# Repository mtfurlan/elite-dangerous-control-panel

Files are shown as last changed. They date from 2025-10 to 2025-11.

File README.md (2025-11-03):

# RP2040 TinyUSB HID elite dangerous controller
A control panel for Elite Dangerous.

It takes input from the game's
[Status.json](https://elite-journal.readthedocs.io/en/latest/Status%20File.html)
and sends it over HID to the control panel.

That way we can have switches that act like buttons, as well as LEDs.

## HID notes
I had some Issues getting tinyusb working, I tried adafruit's port under platformio and too many things there were annoying and broken.
So eventaully I just ended up using the rp2040 pico-sdk and tinyusb directly.

`.lvimrc` to configure [`vim-ale`](https://github.com/dense-analysis/ale) cause it can't fully get stuff from `compile_commands.json` [yet](https://github.com/dense-analysis/ale/issues/3328)

### USB HID
* [Introduction to HID report descriptors](https://docs.kernel.org/hid/hidintro.html)
* spec
  * [HID 1.11 spec](https://www.usb.org/sites/default/files/hid1_11.pdf)
  * [HID Usage Tables](https://usb.org/sites/default/files/hut1_6.pdf): has usage pages and usage tags and other stuff

* input: data from device -> host like keyboard or joystick
* output: data from host -> device, like keyboard LEDs
* feature report: other stuff
  > "Feature"s are not meant to be consumed by the end user and define configuration options for the device.

#### linux support of HID
Unfortunately, linux doesn't support stuff like weird simulation buttons, so
the only real options are gamepad buttons or keyboard buttons.

[Look at how little of sim is covered](https://github.com/torvalds/linux/blob/master/drivers/hid/hid-input.c#L797-L806).

#### decoding descriptor reports
* [hidrdd](https://github.com/abend0c1/hidrdd)
  * `alias hidrdd="rexx ~/src/hidrdd/rd.rex -i ~/src/hidrdd/rd.conf --no-struct"`
  * `hidrdd -bf /sys/bus/hid/devices/0003\:CAFE\:4003.0060/report_descriptor`
* [online USB Descriptor and Request Parser](http://eleccelerator.com/usbdescreqparser/)
  * `xxd -p /sys/bus/hid/devices/0003\:CAFE\:4003.0060/report_descriptor | tr -d '\n' | copyToClipboard`

#### host side hid tools
```
hidapitester --vidpid CAFE:4003 --open --length 3 --send-output 1,0x00,0x0
```

python [hid](https://pypi.org/project/hid/) wraps [libusb hidapi](https://libusb.info/hidapi/group__API.html)
```
import hid
with hid.Device(vid, pid) as h:
    h.write(bytes([0x01, 0x42, 0, 0, 0]))
```

udev:
```
SUBSYSTEMS=="usb", ATTRS{idVendor}=="cafe", MODE:="0666"
```

### Fun facts about windows
windows will just disregard hid devices with vendor pages without usage min/max, even though it's a vendor page

In actual windows, you can see a (misspelled) error in the device manager.

In wine, I'm not sure how to get any error message.

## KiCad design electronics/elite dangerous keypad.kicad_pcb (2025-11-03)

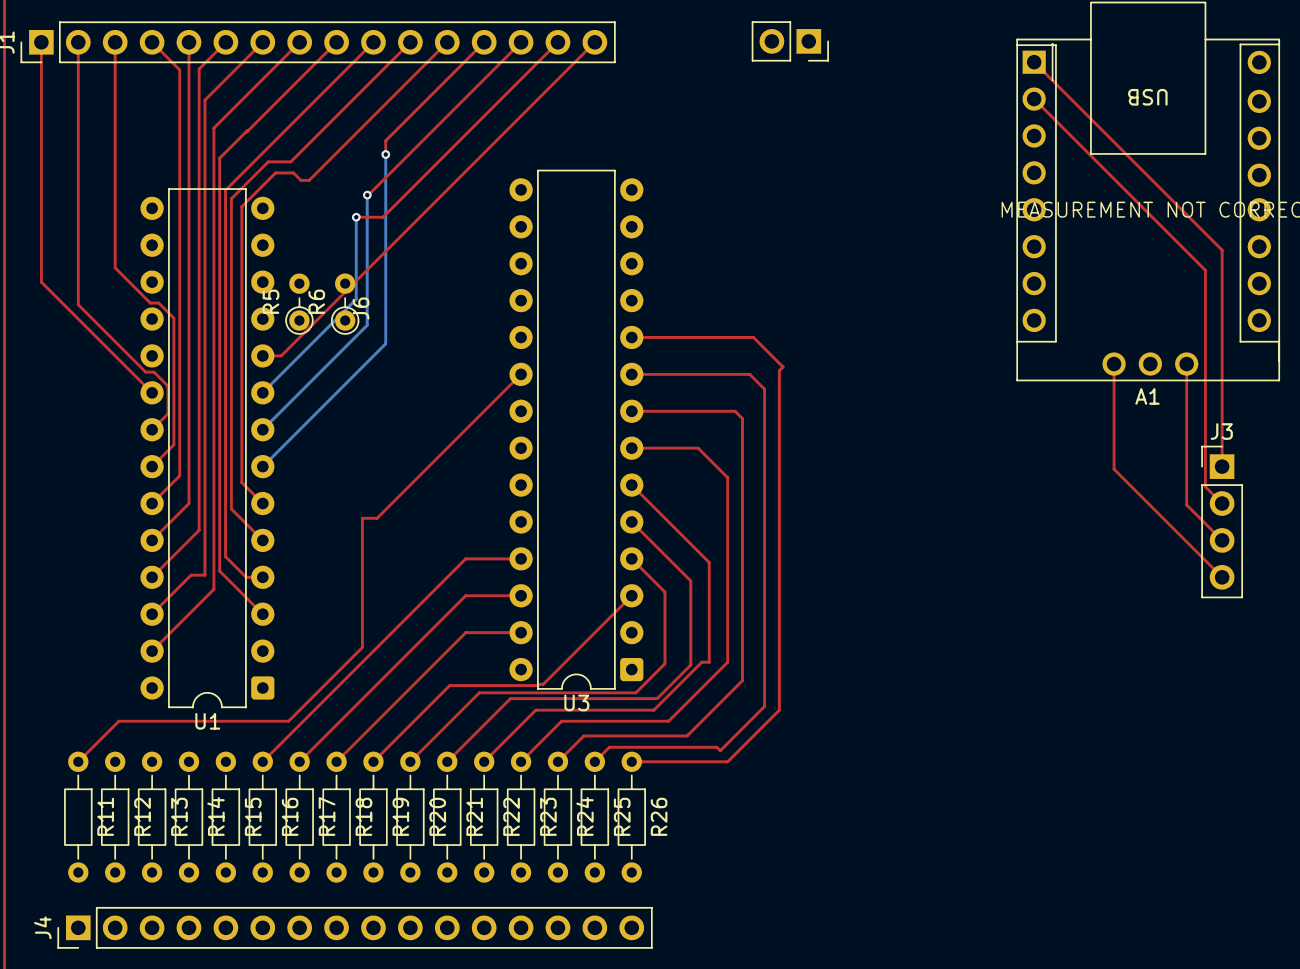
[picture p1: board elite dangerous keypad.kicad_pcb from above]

Board: 2 copper layers, 25 parts (0 on the bottom side), 55 nets.

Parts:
A1: Tiny2040; Arduino_Nano
J1: button; PinHeader_1x16_P2.54mm_Vertical
J3: swd debug; PinHeader_1x04_P2.54mm_Vertical
J4: led; PinHeader_1x16_P2.54mm_Vertical
J6: Conn_01x02; PinSocket_1x02_P2.54mm_Vertical
R5, R6: 1k5; R_Axial_DIN0204_L3.6mm_D1.6mm_P2.54mm_Vertical
R11, R12, R13, R14, R15, R16, R17, R18, R19, R20, R21, R22, R23, R24, R25, R26: R; R_Axial_DIN0204_L3.6mm_D1.6mm_P7.62mm_Horizontal
U1, U3: MCP23018x-x-SP; DIP-28_W7.62mm

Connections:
+5V: A1.1 (5V), J3.1, J6.1, R5.1, R6.1, U1.11 (V_{DD}), U1.16 (~RESET), U3.11 (V_{DD}), U3.15 (ADDR), U3.16 (~RESET)
/B0: J1.1, U1.20 (GPA0)
/B1: J1.2, U1.21 (GPA1)
/B2: J1.3, U1.22 (GPA2)
/B3: J1.4, U1.23 (GPA3)
/B4: J1.5, U1.24 (GPA4)
/B5: J1.6, U1.25 (GPA5)
/B6: J1.7, U1.26 (GPA6)
/B7: J1.8, U1.27 (GPA7)
/B8: J1.9, U1.3 (GPB0)
/B9: J1.10, U1.4 (GPB1)
/B10: J1.11, U1.5 (GPB2)
/B11: J1.12, U1.6 (GPB3)
/B12: J1.13, U1.7 (GPB4)
/B13: J1.14, U1.8 (GPB5)
/B14: J1.15, U1.9 (GPB6)
/B15: J1.16, U1.10 (GPB7)
/L0: R11.1, U3.20 (GPA0)
/L1: R12.1, U3.21 (GPA1)
/L2: R13.1, U3.22 (GPA2)
/L3: R14.1, U3.23 (GPA3)
/L4: R15.1, U3.24 (GPA4)
/L5: R16.1, U3.25 (GPA5)
/L6: R17.1, U3.26 (GPA6)
/L7: R18.1, U3.27 (GPA7)
/L8: R19.1, U3.3 (GPB0)
/L9: R20.1, U3.4 (GPB1)
/L10: R21.1, U3.5 (GPB2)
/L11: R22.1, U3.6 (GPB3)
/L12: R23.1, U3.7 (GPB4)
/L13: R24.1, U3.8 (GPB5)
/L14: R25.1, U3.9 (GPB6)
/L15: R26.1, U3.10 (GPB7)
/MCU_INPUT_INT: A1.10 (6), U1.19 (INTA)
/SCL: A1.11 (5), R5.2, U1.12 (SCL), U3.12 (SCL)
/SDA: A1.12 (4), R6.2, U1.13 (SDA), U3.13 (SDA)
GND: A1.2 (GND), J3.2, J6.2, U1.1 (V_{SS}), U1.15 (ADDR), U3.1 (V_{SS})
unnamed: A1.SWD, J3.3
unnamed: A1.SWC, J3.4
unnamed: J4.1, R11.2
unnamed: J4.2, R12.2
unnamed: J4.3, R13.2
unnamed: J4.4, R14.2
unnamed: J4.5, R15.2
unnamed: J4.6, R16.2
unnamed: J4.7, R17.2
unnamed: J4.8, R18.2
unnamed: J4.9, R19.2
unnamed: J4.10, R20.2
unnamed: J4.11, R21.2
unnamed: J4.12, R22.2
unnamed: J4.13, R23.2
unnamed: J4.14, R24.2
unnamed: J4.15, R25.2
unnamed: J4.16, R26.2

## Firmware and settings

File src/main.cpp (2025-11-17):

#include <stdlib.h>

#include <bsp/board_api.h>
#include <hardware/i2c.h>
#include <pico/stdio.h>
#include <tusb.h>

#include <mcp23017.h>

#include "buttons.h"
#include "config_button.h"
#include "config_quadrature.h"
#include "config_smart.h"
#include "hid.h"
#include "led.h"
#include "usb_descriptors.h"


#define MCP_INPUT         0x20
#define MCP_OUTPUT        0x27
#define MCP_INPUT_IRQ_PIN 6


#define I2C_GPIO_PIN_SDA 4
#define I2C_GPIO_PIN_SCL 5


void hid_task(bool dirty, uint16_t* inputs);
static void send_hid_report(uint8_t report_id, uint16_t btn);


static Config* config[] = {
    new ConfigSmart(1,
                    1,
                    1,
                    [](hid_incoming_data_t* data) -> bool {
                        return data->Flags.fields.Landing_Gear_Down;
                    }),
    new ConfigSmart(2,
                    2,
                    2,
                    [](hid_incoming_data_t* data) -> bool {
                        return data->Flags.fields.LightsOn;
                    }),
    new ConfigSmart(3,
                    3,
                    3,
                    [](hid_incoming_data_t* data) -> bool {
                        return data->Flags.fields.Night_Vision;
                    }),
    new ConfigSmart(4,
                    4,
                    4,
                    [](hid_incoming_data_t* data) -> bool {
                        return data->Flags.fields.Hardpoints_Deployed;
                    }),
    new ConfigSmart(5,
                    5,
                    5,
                    [](hid_incoming_data_t* data) -> bool {
                        return data->Flags.fields.Cargo_Scoop_Deployed;
                    }),
    new ConfigButton(6, 6),
    new ConfigButton(7, 7),
    new ConfigButton(8, 8),
    new ConfigButton(9, 9),
    new ConfigButton(10, 10),
    new ConfigButton(11, 11),
    new ConfigButton(12, 12),
    new ConfigButton(13, 13),
    new ConfigQuadrature(14, 15, 14, 15),
    new ConfigButton(16, 16),
};

static led_state_t led_state = BLINK_NOT_MOUNTED;
static hid_incoming_data_t hid_incoming_data;


int main(void)
{
    // Initialize TinyUSB stack
    board_init();
    tusb_init();


    i2c_init(i2c0, 400000);
    gpio_set_function(I2C_GPIO_PIN_SDA, GPIO_FUNC_I2C);
    gpio_set_function(I2C_GPIO_PIN_SCL, GPIO_FUNC_I2C);
    gpio_pull_up(I2C_GPIO_PIN_SDA);
    gpio_pull_up(I2C_GPIO_PIN_SCL);

    int err = 0;
    err |= buttons_init(MCP_INPUT_IRQ_PIN, i2c0, MCP_INPUT);
    err |= led_init(i2c0, MCP_OUTPUT);

    // TinyUSB board init callback after init
    if (board_init_after_tusb) {
        board_init_after_tusb();
    }

    // let pico sdk use the first cdc interface for std io
    stdio_init_all();

    tud_task();

    bool fail = false;
    if (err != 0) {
        fail = true;
    } else {
        for (size_t i = 0; i < TU_ARRAY_SIZE(config); ++i) {
            Config* c = config[i];
            if ((err = c->init()) != 0) {
                sleep_ms(1000);
                printf("init failed for config %d bad: %d\n", i, err);
                fail = true;
            }
        }
    }

    if (fail) {
        while (true) {
            tud_task();
            led_error();
            printf("failed to init\n");
        }
    }

    printf("hello running");
    uint16_t button_data = 0;
    uint16_t output;
    uint16_t led_data;

    // main run loop
    while (1) {
        // TinyUSB device task | must be called regurlarly
        tud_task();

        bool dirty = buttons_task(&button_data);

        // input data: hid_incoming_data.leds
        // switch state: button_data
        for (size_t i = 0; i < TU_ARRAY_SIZE(config); ++i) {
            Config* c = config[i];
            dirty |= c->generateOutput(&output, button_data, &hid_incoming_data);
        }


        hid_task(dirty, &output);

        led_data = 0;
        for (size_t i = 0; i < TU_ARRAY_SIZE(config); ++i) {
            Config* c = config[i];
            c->setLED(&led_data, &hid_incoming_data);
        }

        led_task(led_state, led_data);
    }

    // indicate no error
    return 0;
}

//--------------------------------------------------------------------+
// Device callbacks
//--------------------------------------------------------------------+

// Invoked when device is mounted
void tud_mount_cb(void)
{
    led_state = BLINK_MOUNTED;
}

// Invoked when device is unmounted
void tud_umount_cb(void)
{
    led_state = BLINK_NOT_MOUNTED;
}

// Invoked when usb bus is suspended
// remote_wakeup_en : if host allow us  to perform remote wakeup
// Within 7ms, device must draw an average of current less than 2.5 mA from bus
void tud_suspend_cb(bool remote_wakeup_en)
{
    (void)remote_wakeup_en;
    led_state = BLINK_SUSPENDED;
}

// Invoked when usb bus is resumed
void tud_resume_cb(void)
{
    led_state = tud_mounted() ? BLINK_MOUNTED : BLINK_NOT_MOUNTED;
}

//--------------------------------------------------------------------+
// USB HID
//--------------------------------------------------------------------+
// Every 10ms, we will sent 1 report for each HID profile (keyboard, mouse etc ..)
// tud_hid_report_complete_cb() is used to send the next report after previous one is complete
static uint16_t btn;
void hid_task(bool dirty, uint16_t* inputs)
{
    btn = *inputs;
    // Poll every 10ms
    const uint32_t interval_ms = 10;
    static uint32_t start_ms = 0;

    if (!dirty && (board_millis() - start_ms < interval_ms)) {
        return; // not enough time
    }
    start_ms += interval_ms;

    // Remote wakeup
    if (tud_suspended() && btn) {
        // Wake up host if we are in suspend mode
        // and REMOTE_WAKEUP feature is enabled by host
        tud_remote_wakeup();
    } else {
        // Send the 1st of report chain, the rest will be sent by tud_hid_report_complete_cb()
        send_hid_report(REPORT_ID_GAMEPAD, btn);
    }
}

// Invoked when sent REPORT successfully to host
// Application can use this to send the next report
// Note: For composite reports, report[0] is report ID
void tud_hid_report_complete_cb(uint8_t instance, uint8_t const* report, uint16_t len)
{
    (void)instance;
    (void)len;

    uint8_t next_report_id = report[0] + 1u;

    if (next_report_id < REPORT_ID_COUNT) {
        send_hid_report(next_report_id, btn);
    }
}

// Invoked when received GET_REPORT control request
// Application must fill buffer report's content and return its length.
// Return zero will cause the stack to STALL request
uint16_t tud_hid_get_report_cb(uint8_t instance,
                               uint8_t report_id,
                               hid_report_type_t report_type,
                               uint8_t* buffer,
                               uint16_t reqlen)
{
    // TODO not Implemented
    (void)instance;
    (void)report_id;
    (void)report_type;
    (void)buffer;
    (void)reqlen;

    return 0;
}

// Invoked when received SET_REPORT control request or
// received data on OUT endpoint ( Report ID = 0, Type = 0 )
void tud_hid_set_report_cb(uint8_t instance,
                           uint8_t report_id,
                           hid_report_type_t report_type,
                           uint8_t const* buffer,
                           uint16_t bufsize)
{
    (void)instance;

    if (report_type == HID_REPORT_TYPE_OUTPUT) {
        // Set keyboard LED e.g Capslock, Numlock etc...
        if (report_id == REPORT_ID_GAMEPAD) {
            // bufsize should be (at least) 1
            if (bufsize != sizeof(hid_incoming_data_t)) {
                printf("got a weird size data from hid, reporrt id %d, expected %d bytes, got %d\n",
                       report_id,
                       sizeof(hid_incoming_data_t),
                       bufsize);
                return;
            }

            hid_incoming_data = *(hid_incoming_data_t*)buffer;

            printf("got data\n");
        } else {
            printf("got unexpected output repoort for id %d", report_id);
        }
    }
}

static void send_hid_report(uint8_t report_id, uint16_t btn)
{
    // skip if hid is not ready yet
    if (!tud_hid_ready())
        return;

    switch (report_id) {
        case REPORT_ID_GAMEPAD: {
            // use to avoid send multiple consecutive zero report for keyboard
            static bool has_gamepad_key = false;

            hid_button_report_t report = {
                .buttons = btn,
            };

            if (btn) {
                tud_hid_report(REPORT_ID_GAMEPAD, &report, sizeof(report));

                has_gamepad_key = true;
            } else {
                if (has_gamepad_key)
                    tud_hid_report(REPORT_ID_GAMEPAD, &report, sizeof(report));
                has_gamepad_key = false;
            }
        } break;

        default:
            break;
    }
}

//--------------------------------------------------------------------+
// USB CDC
//--------------------------------------------------------------------+

// callback when data is received on a CDC interface
void tud_cdc_rx_cb(uint8_t itf)
{
    // allocate buffer for the data in the stack
    uint8_t buf[CFG_TUD_CDC_RX_BUFSIZE];

    printf("RX CDC %d\n", itf);

    // read the available data
    // | IMPORTANT: also do this for CDC0 because otherwise
    // | you won't be able to print anymore to CDC0
    // | next time this function is called
    uint32_t count = tud_cdc_n_read(itf, buf, sizeof(buf));

    // check if the data was received on the second cdc interface
    if (itf == 1) {
        // process the received data
        buf[count] = 0; // null-terminate the string
        // now echo data back to the console on CDC 0
        printf("Received on CDC 1: %s\n", buf);

        // and echo back OK on CDC 1
        tud_cdc_n_write(itf, (uint8_t const*)"OK\r\n", 4);
        tud_cdc_n_write_flush(itf);
    }
}

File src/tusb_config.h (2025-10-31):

/**
 * Copyright (c) 2023 Raspberry Pi (Trading) Ltd.
 *
 * SPDX-License-Identifier: BSD-3-Clause
 */

#ifndef _TUSB_CONFIG_H_
#define _TUSB_CONFIG_H_

#ifdef __cplusplus
extern "C" {
#endif

#define CFG_TUD_ENABLED (1)

// Legacy RHPORT configuration
#define CFG_TUSB_RHPORT0_MODE (OPT_MODE_DEVICE | OPT_MODE_FULL_SPEED)
#ifndef BOARD_TUD_RHPORT
#define BOARD_TUD_RHPORT (0)
#endif
// end legacy RHPORT

//------------------------
// DEVICE CONFIGURATION //
//------------------------
#ifndef CFG_TUD_ENDPOINT0_SIZE
#define CFG_TUD_ENDPOINT0_SIZE (64)
#endif


//------------- CLASS -------------//
#define CFG_TUD_HID    1
#define CFG_TUD_CDC    1
#define CFG_TUD_MSC    0
#define CFG_TUD_MIDI   0
#define CFG_TUD_VENDOR 0

// CDC FIFO size of TX and RX
#define CFG_TUD_CDC_RX_BUFSIZE (TUD_OPT_HIGH_SPEED ? 512 : 64)
#define CFG_TUD_CDC_TX_BUFSIZE (TUD_OPT_HIGH_SPEED ? 512 : 64)

// CDC Endpoint transfer buffer size, more is faster
#define CFG_TUD_CDC_EP_BUFSIZE (TUD_OPT_HIGH_SPEED ? 512 : 64)

// HID buffer size Should be sufficient to hold ID (if any) + Data
#define CFG_TUD_HID_EP_BUFSIZE 16

#ifdef __cplusplus
}
#endif

#endif /* _TUSB_CONFIG_H_ */

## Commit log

2025-10-23 pico-sdk hid_composite example with debugging
2025-10-23 try to do cdc and hid, doesn't work
    [main.c, tusb_config.h]
2025-10-23 modified usb cdc example doesn'tw ork
    [main.c, tusb_config.h]
2025-10-23 button works
2025-10-23 only send a gamepad button event; gdbconfig reset better
    [main.c]
2025-10-27 switch stuff; input stuff works
2025-10-28 buttons and leds work but wine doesn't now?
    [main.c]
2025-10-29 feat: buttons use mcp
2025-10-30 led mcp works
2025-10-30 add kicad schematic
    [elite dangerous keypad.kicad_pcb, elite dangerous keypad.kicad_sch]
2025-10-30 feat: error on init error
    [led.cpp, main.cpp]
2025-10-30 smart button works, but apparently I'm not writing hid buttons properly
    they all show up as button 1
2025-10-30 fix(hid reporting): report data, fix hid desc report
    [main.cpp]
2025-10-30 smart button works!
2025-11-03 schematic for cardboard box version
    [elite dangerous keypad.kicad_pcb, elite dangerous keypad.kicad_sch]
2025-11-03 feat: button config better ish
2025-11-08 fix(hid): last button works again
    skipped button 13 wrong
2025-11-12 feat(buttons): add buttons_read function
2025-11-12 fix(config): 1 index button/led pins for consistancy
    [main.cpp]
2025-11-15 refactor: use cpp classes for input config
    instead of struct array and switches to handle a mode enum, use classes
2025-11-15 refactor(classes): split up led and button better
    now we have the config base class, an led class, and a button class
    smart switch takes led and button and extends the deciding part
2025-11-15 refactor: VButton class to handle virtual buttons
    ConfigSmart is *so much* simpler and everything is easier to read now
2025-11-15 refactor: config btn track last state, vbutton better
2025-11-16 chore: git diff exclude kicad files
2025-11-16 feat(electronics): quadrature schematic
    [KY-040.kicad_sch, elite dangerous keypad.kicad_sch]
2025-11-16 feat(quadrature): use quad encoders as buttons
    cpp types are weird
2025-11-17 docs(electronics): label KY-040 resistors
    [KY-040.kicad_sch]
2025-12-10 docs(electronics): reformat for readability
    [KY-040.kicad_sch, elite dangerous keypad.kicad_sch]
